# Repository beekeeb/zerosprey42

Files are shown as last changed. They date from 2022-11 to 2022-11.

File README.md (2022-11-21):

# Zerosprey42 Keyboard

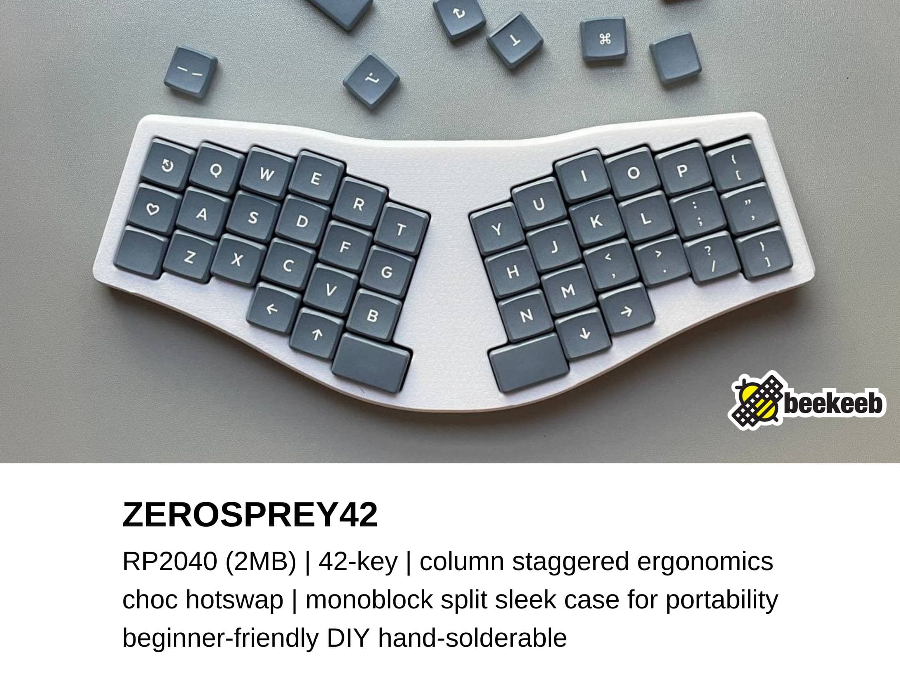
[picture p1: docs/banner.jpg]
Zerosprey42 Keyboard


Zerosprey42 Keyboard is a 42-key, wired, beginner friendly, choc v1 hotswap, MonoBlockSplit (Unibody), column-staggered, DIY low-profile mechanical keyboard. It balances between portability and ergonomics with a sleek travel case. This is a remix of ebastler‘s [osprey](https://github.com/ebastler/osprey) with a low cost RP2040-Zero. 

The development of this project is sponsored by [PCBWay](https://pcbway.com/g/beekeeb) (affiliate link).

## Quick Links

* [Build guide](https://docs.beekeeb.com/zerosprey42-keyboard#build-guide)
* [Precompiled firmware](https://docs.beekeeb.com/zerosprey42-keyboard#precompiled-firmware)
* [beekeeb showcase](https://showcase.beekeeb.com/zerosprey42-keyboard/)

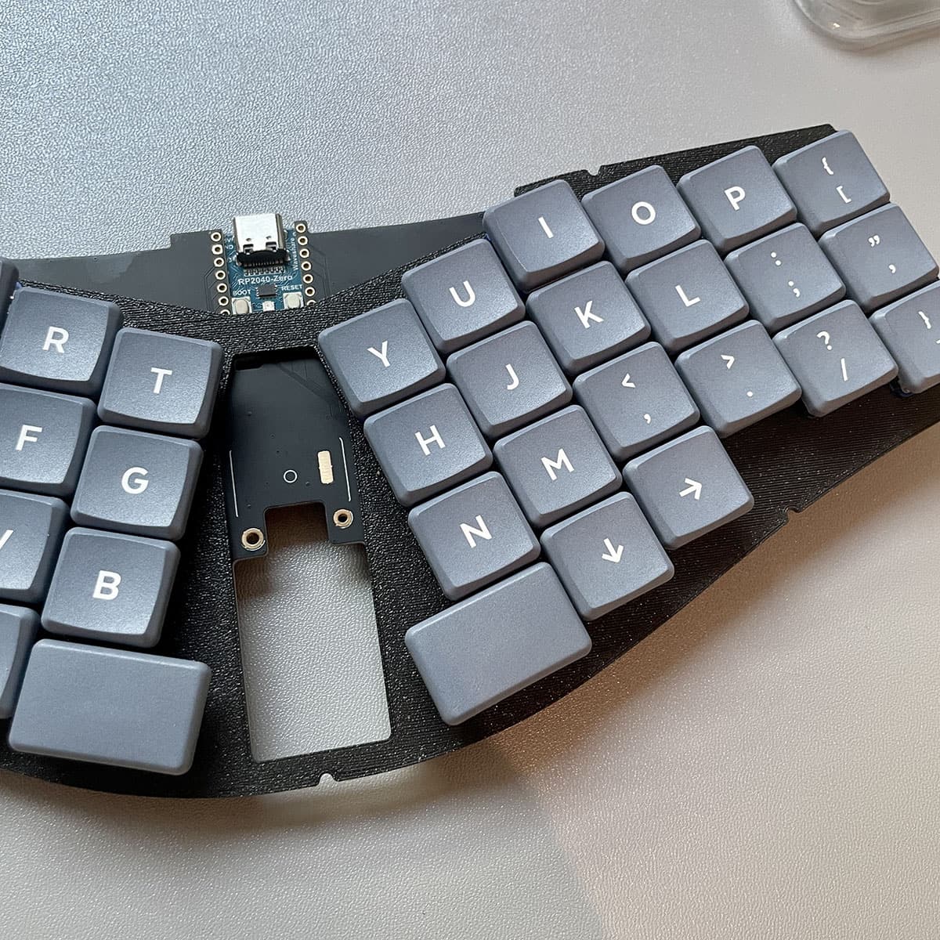
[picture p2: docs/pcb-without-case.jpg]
Zerosprey42 Keyboard PCB


## Features

* MCU Board - WaveShare RP2040-Zero
	* It includes a powerful RP2040 MCU with a lot of flash memory (2MB), so you can enable many QMK features and layers without worrying about the firmware size.
* Easier to solder (for the DIY soldering option)
	* There are very few components/pins to solder for the basic version. You will need to solder diodes, hot swap sockets, and the castellated holes for the RP2040-Zero.
* Choc spacing
	* Key switches are arranged tighter than the standard spacing.
* Ergonomics
	* Slightly angled sides, with a bigger thumb key.
* Monoblock Enclosure for Portability
	* There is an elegant case modified from the original osprey keyboard. It includes a top case, switch plate and a bottom case.
* Firmware
	* QMK and Vial are supported. For advanced users, you should be able to use other firmwares including ZMK, KMK (Python-based), PRK (Ruby-based) and keyberon (Rust-based)

## Bill of Materials (BOM)

Quantity | Item | Notes
--- | --- | ---
1 | Zerosprey42 PCB
1 | WaveShare RP2040-Zero
42 | 1N4148 SOD123 diodes
42 | CPG135001S30 hotswap sockets for choc v1 PG1350
42 | choc v1 key switches
42 | choc v1 keycaps | "choc spacing" required

## Ordering Parts

[DIY kits](https://shop.beekeeb.com/product/zerosprey42-monoblock-rp2040-keyboard/) and [prebuilt keyboards](https://shop.beekeeb.com/product/zerosprey42-monoblock-rp2040-keyboard/) are available at https://beekeeb.shop

If you prefer getting the parts by yourself, you can order the PCB from [PCBWay](https://www.pcbway.com/project/shareproject/Zerosprey42_Keyboard_23ae2219.html) or other PCB manufacturers. 

## Firmware

* [QMK](https://github.com/qmk/qmk_firmware)
* [Vial](https://github.com/beekeeb/vial-qmk-zerosprey42) (based on QMK)
* [ZMK](https://github.com/tubbytwins/zmk-config-zerosprey42) by [tubbytwins](https://github.com/tubbytwins)

For advanced users, other firmwares including KMK (Python/CircuitPython), PRK (Ruby), keyberon (Rust) should be possible.

Precompiled firmware can be found at https://docs.beekeeb.com/zerosprey42-keyboard.

## Boards Preview

<p>
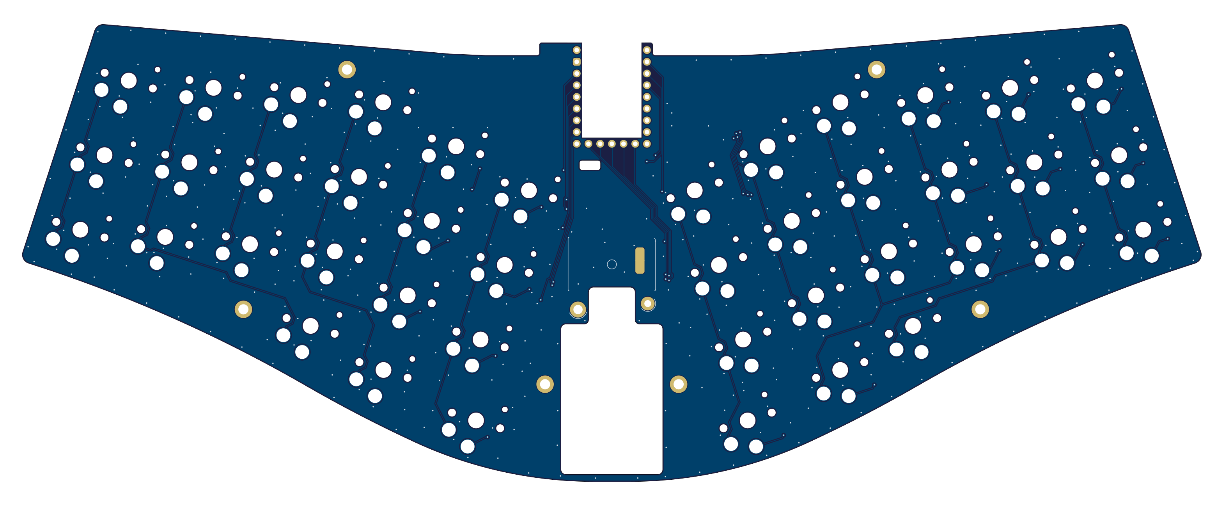
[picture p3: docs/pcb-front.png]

</p>
<p>
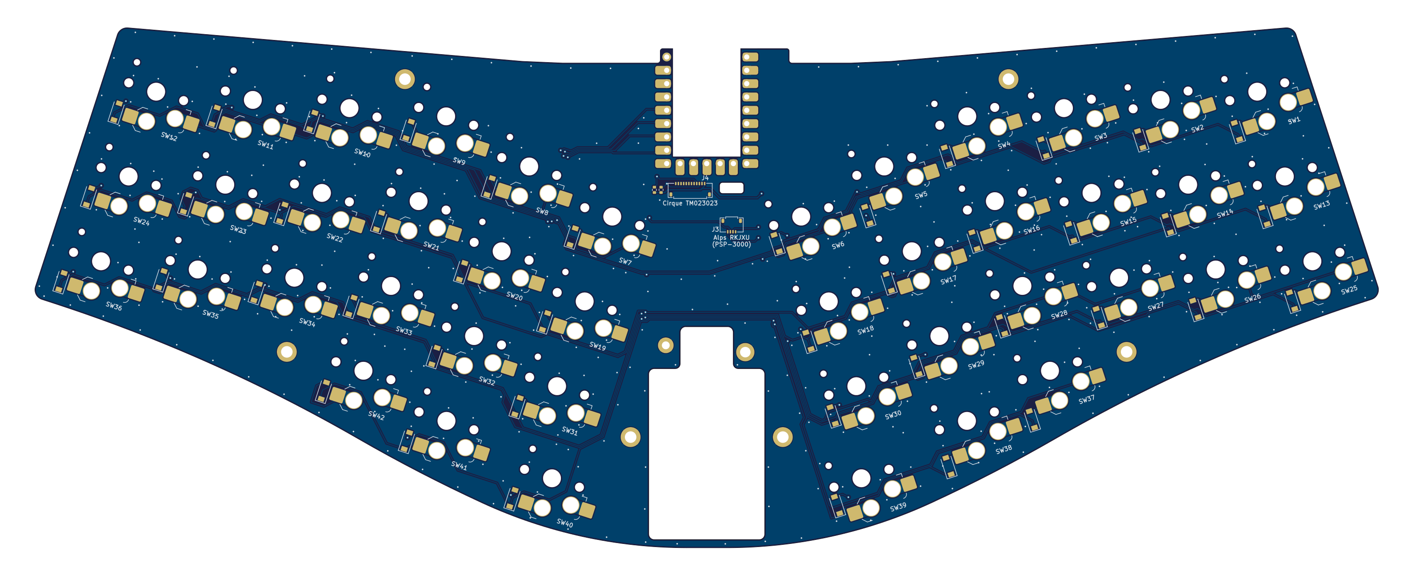
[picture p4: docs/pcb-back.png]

</p>

## License

Logos, external symbols and footprints are not covered by the LICENSE in this repo.

## Sponsors

This open source hardware project is sponsored by

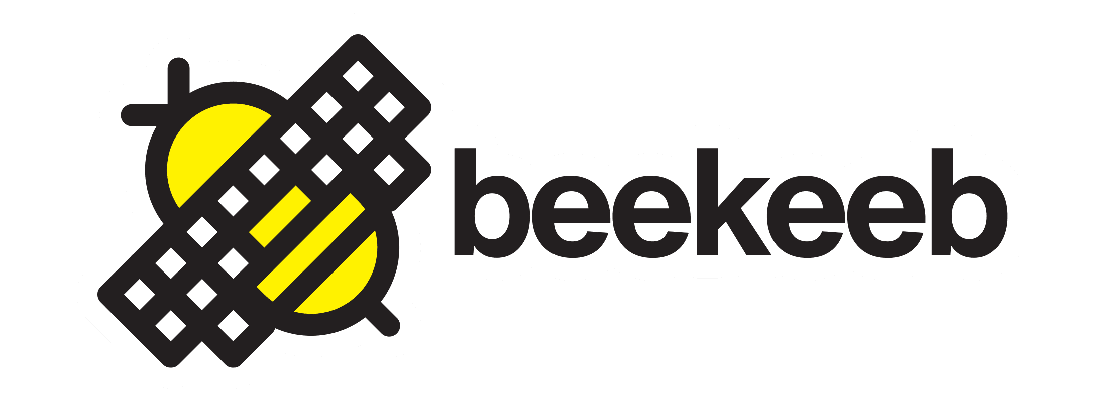
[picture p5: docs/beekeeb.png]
[](https://beekeeb.shop)
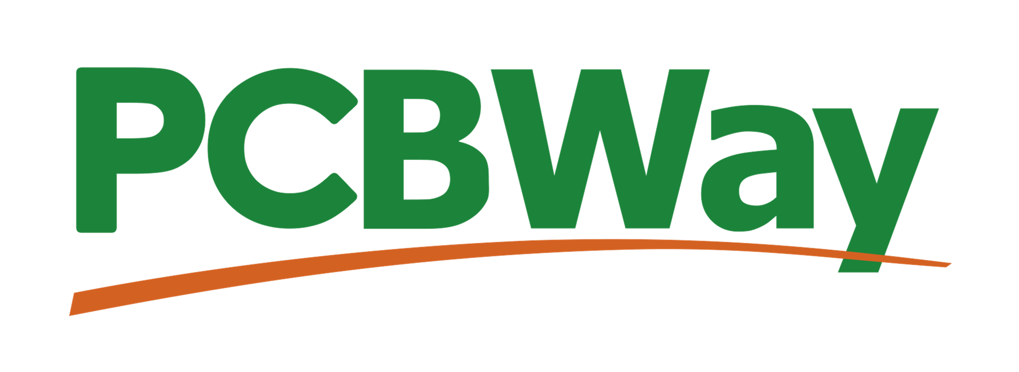
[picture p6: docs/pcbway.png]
[](https://pcbway.com/g/beekeeb)

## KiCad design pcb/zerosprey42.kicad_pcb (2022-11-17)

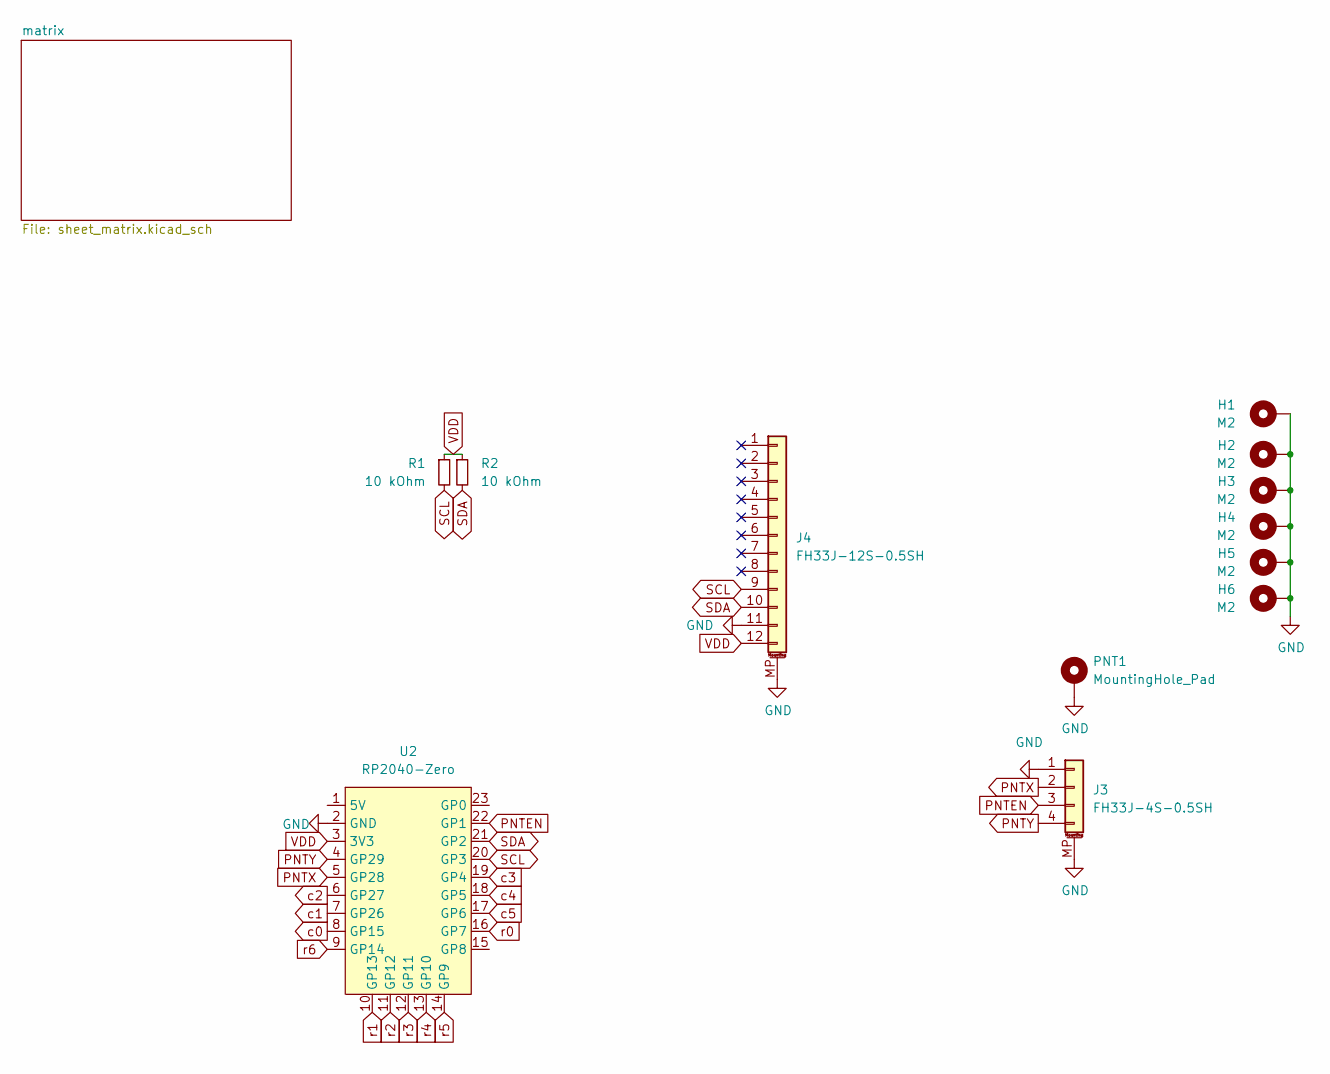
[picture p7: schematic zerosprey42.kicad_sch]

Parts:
H1, H2, H3, H4, H5, H6: M2; MountingHole_2.2mm_M2_DIN965_Pad
J3: FH33J-4S-0.5SH; CON_FH33J-4S-0.5SH
J4: FH33J-12S-0.5SH; CON_FH33J-12S-0.5SH
PNT1: MountingHole_Pad; PNT_RKJXU1210006
R1, R2: 10 kOhm; R_0402_1005Metric; LCSC C25744
U2: RP2040-Zero; rp2040-zero-back

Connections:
GND: H1.1, H2.1, H3.1, H4.1, H5.1, H6.1, J3.1, J3.MP (MountPin), J4.11, J4.MP (MountPin), PNT1.MP, U2.2 (GND)
PNTEN: J3.3, U2.22 (GP1)
PNTX: J3.2, U2.5 (GP28)
PNTY: J3.4, U2.4 (GP29)
SCL: J4.9, R1.2, U2.20 (GP3)
SDA: J4.10, R2.2, U2.21 (GP2)
VDD: J4.12, R1.1, R2.1, U2.3 (3V3)
c0: U2.8 (GP15); also elsewhere on the board
c1: U2.7 (GP26); also elsewhere on the board
c2: U2.6 (GP27); also elsewhere on the board
c3: U2.19 (GP4); also elsewhere on the board
c4: U2.18 (GP5); also elsewhere on the board
c5: U2.17 (GP6); also elsewhere on the board
r0: U2.16 (GP7); also elsewhere on the board
r1: U2.10 (GP13); also elsewhere on the board
r2: U2.11 (GP12); also elsewhere on the board
r3: U2.12 (GP11); also elsewhere on the board
r4: U2.13 (GP10); also elsewhere on the board
r5: U2.14 (GP9); also elsewhere on the board
r6: U2.9 (GP14); also elsewhere on the board

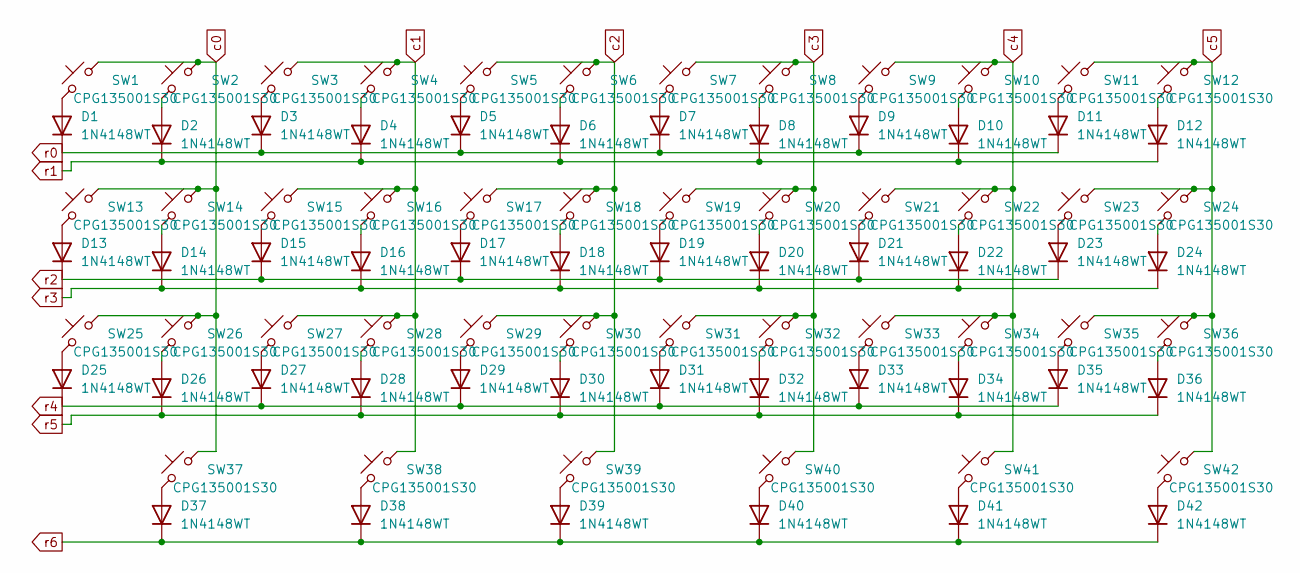
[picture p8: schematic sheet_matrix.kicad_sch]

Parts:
D1, D2, D3, D4, D5, D6, D7, D8, D9, D10, D11, D12, D13, D14, D15, D16, D17, D18, D19, D20, D21, D22, D23, D24, D25, D26, D27, D28, D29, D30, D31, D32, D33, D34, D35, D36, D37, D38, D39, D40, D41, D42: 1N4148WT; D_SOD-523
SW1, SW2, SW3, SW4, SW5, SW6, SW7, SW8, SW9, SW10, SW11, SW12, SW13, SW14, SW15, SW16, SW17, SW18, SW19, SW20, SW21, SW22, SW23, SW24, SW25, SW26, SW27, SW28, SW29, SW30, SW31, SW32, SW33, SW34, SW35, SW36, SW37, SW38, SW41, SW42: CPG135001S30; SW_choc_HS_1u
SW39, SW40: CPG135001S30; SW_choc_HS_1.5u

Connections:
unnamed: D1.2 (A), SW1.2
unnamed: D2.2 (A), SW2.2
unnamed: D3.2 (A), SW3.2
unnamed: D4.2 (A), SW4.2
unnamed: D5.2 (A), SW5.2
unnamed: D6.2 (A), SW6.2
unnamed: D7.2 (A), SW7.2
unnamed: D8.2 (A), SW8.2
unnamed: D9.2 (A), SW9.2
unnamed: D10.2 (A), SW10.2
unnamed: D11.2 (A), SW11.2
unnamed: D12.2 (A), SW12.2
unnamed: D13.2 (A), SW13.2
unnamed: D14.2 (A), SW14.2
unnamed: D15.2 (A), SW15.2
unnamed: D16.2 (A), SW16.2
unnamed: D17.2 (A), SW17.2
unnamed: D18.2 (A), SW18.2
unnamed: D19.2 (A), SW19.2
unnamed: D20.2 (A), SW20.2
unnamed: D21.2 (A), SW21.2
unnamed: D22.2 (A), SW22.2
unnamed: D23.2 (A), SW23.2
unnamed: D24.2 (A), SW24.2
unnamed: D25.2 (A), SW25.2
unnamed: D26.2 (A), SW26.2
unnamed: D27.2 (A), SW27.2
unnamed: D28.2 (A), SW28.2
unnamed: D29.2 (A), SW29.2
unnamed: D30.2 (A), SW30.2
unnamed: D31.2 (A), SW31.2
unnamed: D32.2 (A), SW32.2
unnamed: D33.2 (A), SW33.2
unnamed: D34.2 (A), SW34.2
unnamed: D35.2 (A), SW35.2
unnamed: D36.2 (A), SW36.2
unnamed: D37.2 (A), SW37.2
unnamed: D38.2 (A), SW38.2
unnamed: D39.2 (A), SW39.2
unnamed: D40.2 (A), SW40.2
unnamed: D41.2 (A), SW41.2
unnamed: D42.2 (A), SW42.2
c0: SW1.1, SW2.1, SW13.1, SW14.1, SW25.1, SW26.1, SW37.1; also elsewhere on the board
c1: SW3.1, SW4.1, SW15.1, SW16.1, SW27.1, SW28.1, SW38.1; also elsewhere on the board
c2: SW5.1, SW6.1, SW17.1, SW18.1, SW29.1, SW30.1, SW39.1; also elsewhere on the board
c3: SW7.1, SW8.1, SW19.1, SW20.1, SW31.1, SW32.1, SW40.1; also elsewhere on the board
c4: SW9.1, SW10.1, SW21.1, SW22.1, SW33.1, SW34.1, SW41.1; also elsewhere on the board
c5: SW11.1, SW12.1, SW23.1, SW24.1, SW35.1, SW36.1, SW42.1; also elsewhere on the board
r0: D1.1 (K), D3.1 (K), D5.1 (K), D7.1 (K), D9.1 (K), D11.1 (K); also elsewhere on the board
r1: D2.1 (K), D4.1 (K), D6.1 (K), D8.1 (K), D10.1 (K), D12.1 (K); also elsewhere on the board
r2: D13.1 (K), D15.1 (K), D17.1 (K), D19.1 (K), D21.1 (K), D23.1 (K); also elsewhere on the board
r3: D14.1 (K), D16.1 (K), D18.1 (K), D20.1 (K), D22.1 (K), D24.1 (K); also elsewhere on the board
r4: D25.1 (K), D27.1 (K), D29.1 (K), D31.1 (K), D33.1 (K), D35.1 (K); also elsewhere on the board
r5: D26.1 (K), D28.1 (K), D30.1 (K), D32.1 (K), D34.1 (K), D36.1 (K); also elsewhere on the board
r6: D37.1 (K), D38.1 (K), D39.1 (K), D40.1 (K), D41.1 (K), D42.1 (K); also elsewhere on the board

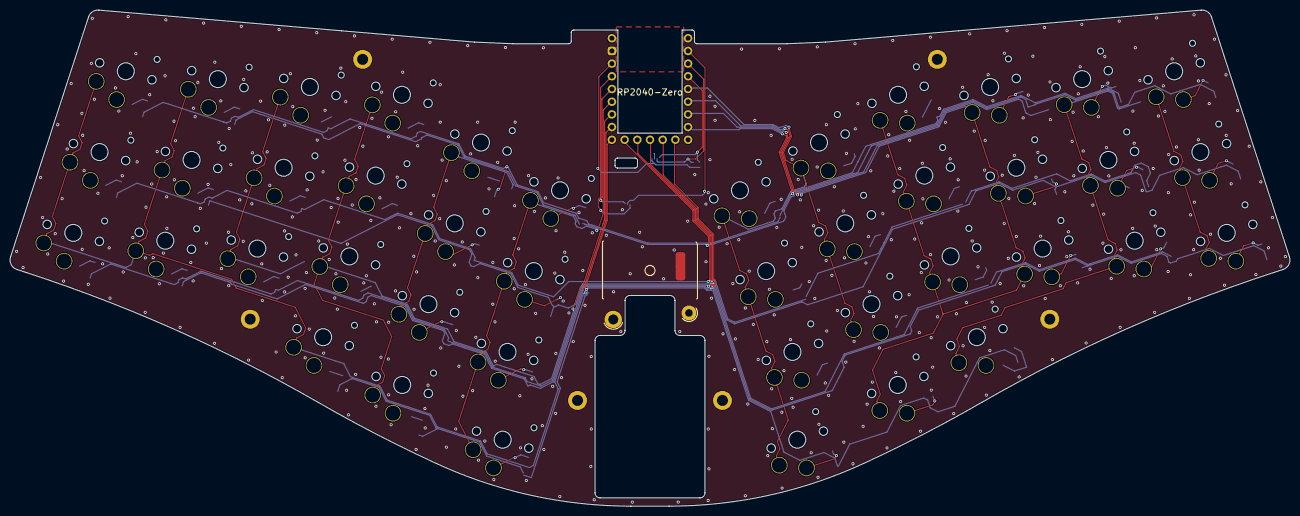
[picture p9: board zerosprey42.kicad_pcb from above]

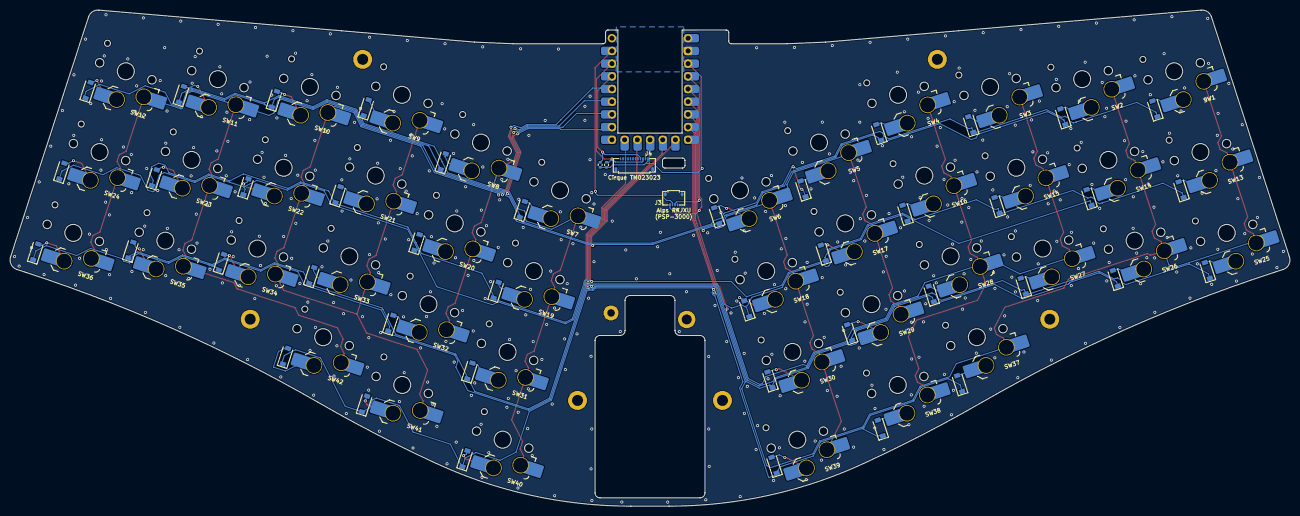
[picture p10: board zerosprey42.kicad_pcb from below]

Board: 2 copper layers, 256.1 x 99.3 mm, 96 parts (92 on the bottom side), 62 nets.
